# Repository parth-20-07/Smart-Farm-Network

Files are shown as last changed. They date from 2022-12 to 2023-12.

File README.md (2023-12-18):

<!-- omit from toc -->
# Smart Farm Network

**Table of Contents**

- [Introduction](#introduction)
- [Sensor Node](#sensor-node)
  - [Hardware Components](#hardware-components)
  - [Schematic](#schematic)
  - [PCB Design](#pcb-design)
- [Server Functionality](#server-functionality)
  - [Core Functions](#core-functions)
- [Setup and Operation](#setup-and-operation)
- [Data Handling and Alerts](#data-handling-and-alerts)
- [Customization and Expansion](#customization-and-expansion)
- [License](#license)
- [Design Details](#design-details)

# Introduction
The Smart Farm Network is a cutting-edge agricultural monitoring system designed to provide real-time insights into environmental conditions. Using a network of sensor nodes and a central server, it delivers detailed data analysis to help manage and optimize farming operations.

# Sensor Node
Equipped with sensors for temperature, humidity, lux, and CO2, each node collects data at set intervals. An integrated RTC ensures accurate timestamping. The nodes communicate with the server using BLE technology.

## Hardware Components
- **MicroUSB for Charging:** Ensures easy and accessible charging.
- **Battery Management:** Monitors and manages battery levels.
- **Power Conversion Units:** Provide the necessary voltages for different components.
- **ESP32 WROOM Module:** Processes and transmits the sensor data.
- **MicroSD Card Slot:** Enables data logging and storage.

## Schematic

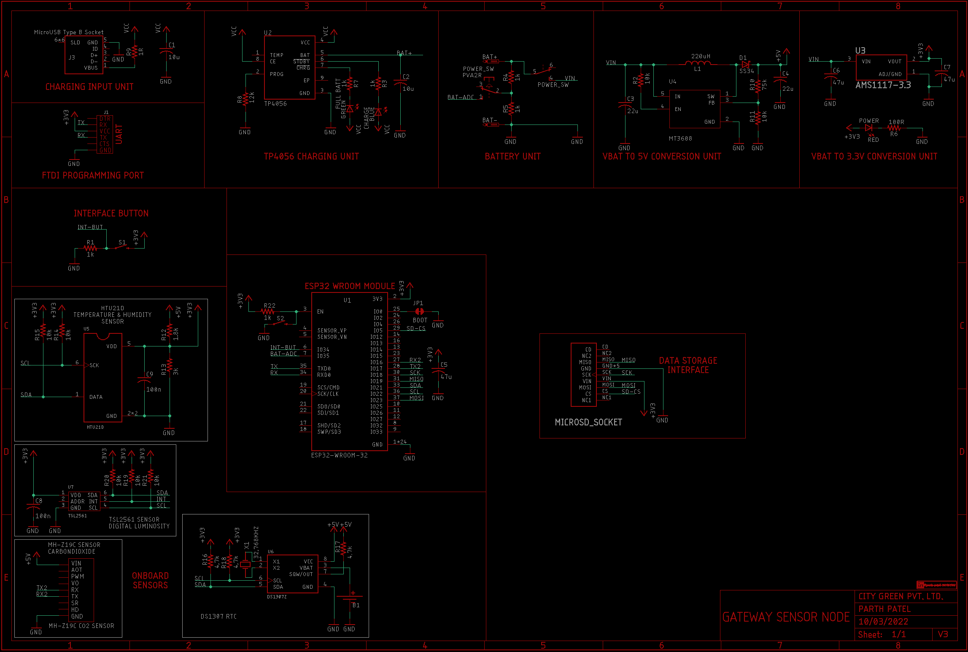
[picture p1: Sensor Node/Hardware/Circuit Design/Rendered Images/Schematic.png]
schematic


## PCB Design

**PCB Top View**

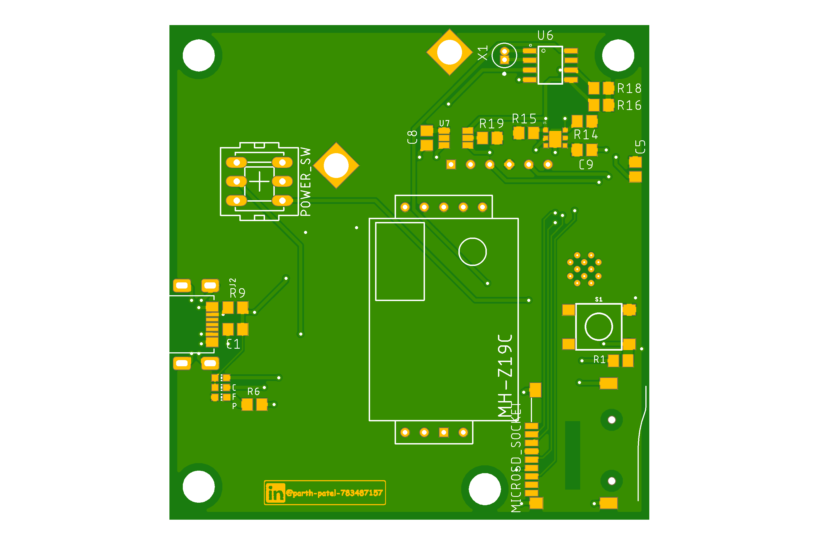
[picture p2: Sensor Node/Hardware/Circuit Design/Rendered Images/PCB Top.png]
pcb-top


**PCB Bottom View**

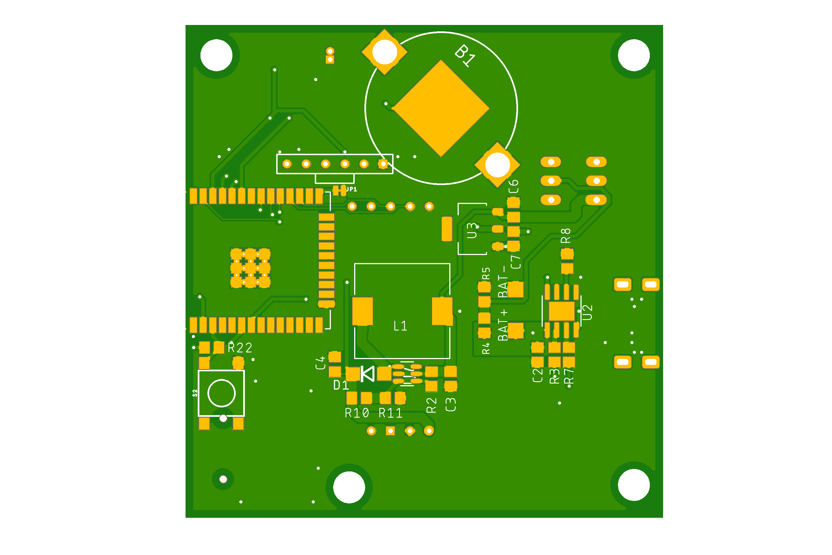
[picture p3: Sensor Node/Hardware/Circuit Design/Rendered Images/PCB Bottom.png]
pcb-bottom


# Server Functionality
The server firmware manages data from over 50 nodes, calculating averages, and issuing alerts if readings exceed thresholds. It features:

## Core Functions
- **Data Processing:** Analyzes incoming data and manages MQTT connections to Digital Ocean for cloud uploads.
- **Display Control:** Updates the HMI display with real-time data and alert statuses.
- **Configuration Management:** Offers a web server interface for device configuration.
- **OTA Updates:** Maintains system integrity with the latest firmware updates.

# Setup and Operation
1. **Assembling Sensor Nodes:** Follow the provided schematics to assemble the hardware.
2. **Installing Firmware:** Flash the sensor nodes and server with the respective firmware.
3. **Configuring the Network:** Connect the nodes to the server via BLE and set up the server's Wi-Fi and MQTT settings.
4. **Launching the System:** Power up the system, and it begins automatic data collection and analysis.

# Data Handling and Alerts
The system stores data in microSD cards and uploads it to the cloud. It calculates average values and displays alerts on the HMI screen if parameters exceed set thresholds.

# Customization and Expansion
The firmware's modular design allows for easy addition of new sensors or communication protocols.

# License
This project is licensed under the GNU General Public License v3.0. See [LICENSE.md](LICENSE.md) for details.

# Design Details

- Designed for: City Green Private Ltd.
- Designed by: [Parth Patel](mailto:parth.pmech@gmail.com)

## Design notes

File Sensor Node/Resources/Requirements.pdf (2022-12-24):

## BLE Node Features

1. Block Diagram:

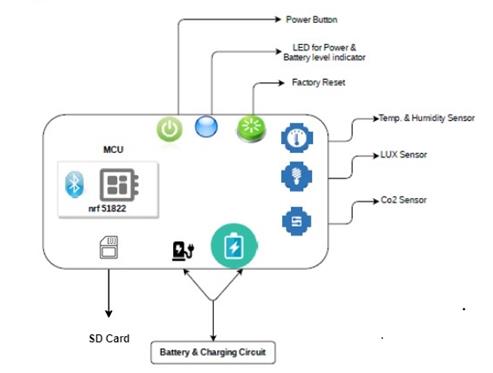
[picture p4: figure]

2. Node Should Send Data to Mobile & Gateway

Node Type

Node ID
Time Stamp
Sensor Data
3. If any of them (Mobile & Gateway) Not in Connection will store data up-to 10 days @ 5 min interval.
4. When connection comes back then it will send data again.
5. Sleep Mode enable when there is no connection.
6. Battery can be a 500mAH-1000mAH Rechargeable Li-Po Battery should charge within 1-2 Hr with Backup Of 5-6 Months.
7. LED Indicator for Power & Connection & Battery Level indicator. (2 LED with Multiple Color Combination)

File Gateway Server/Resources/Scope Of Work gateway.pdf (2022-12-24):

### Scope Of Work Gateway:-P1

It is capable of collecting data from several nodes via the BLE interface. It can store and send collected data to the cloud platform through WiFi. It will also feature a display unit for farm status.
Required Features:
1. Updating Wi-Fi Credentials via a html webpage.
2. The web page design is attached here

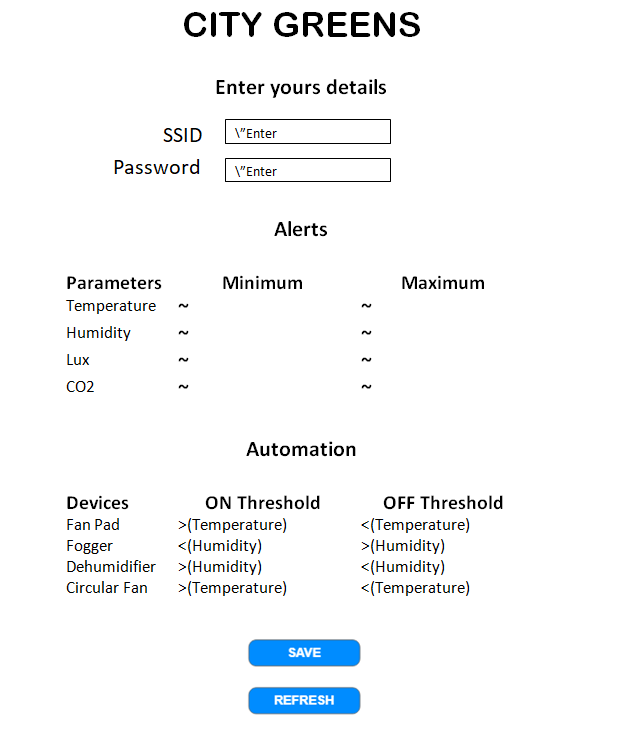
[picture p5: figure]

3. It save the Wi-Fi credentials & alerts data to its internal memory

4. It will check for OTA firmware updates via GitHub
5. Display Screen will Initialise
6. Scan for BLE nodes, identify our sensor nodes, make a connection with them and collect data via BLE
7. It will receive data from 8 Nodes Via BLE Communication.
8. Display Screen Design is shown below

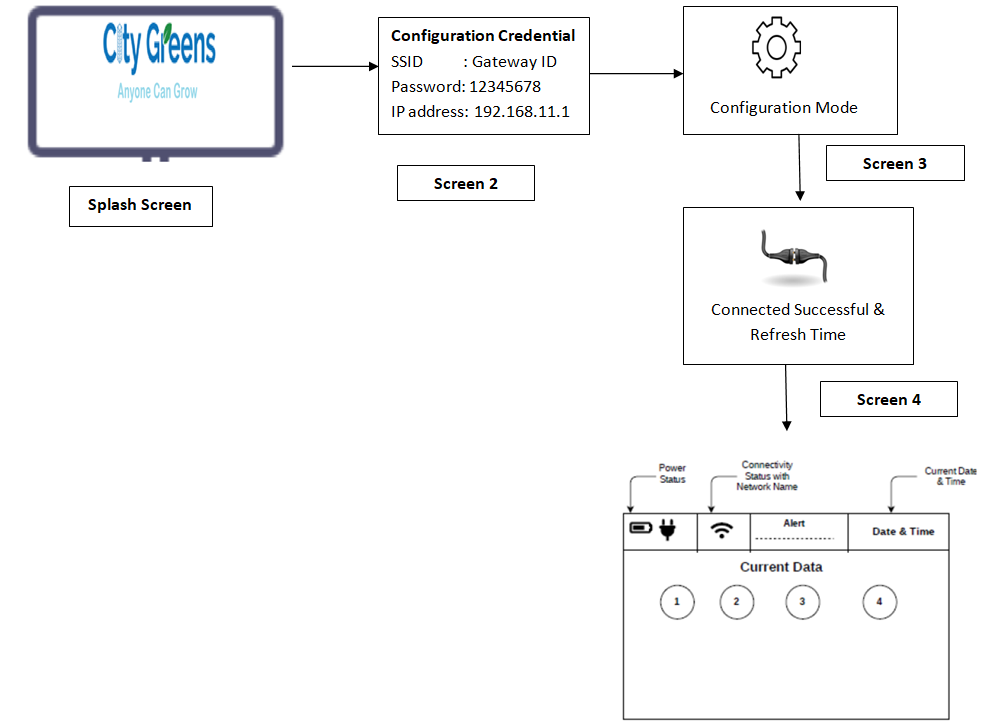
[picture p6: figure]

9. It will save/log the data to an SD card in .csv/.txt format. 10.Installation of MQTT software over the server (Digital Ocean Droplet).
11. The device will publish saved data to the cloud via MQTT.
12.It has a Temp./humidity (HTU21D) sensor on the PCB
13.Power Supply has 12V Battery (Li-ion 2500mAh-3s-11.1v-3c-3S1P Protected Battery Pack) with 12V 2A AC Adaptor
14.RTC will be used to update time.
15.There are three Push Buttons used in the gateway
Reset: it reset the settings of gateway & device will start from its default state; Configure button: it will be used as a manual interrupt to firmware for Wi-Fi & Alert Data Updated by User.
Power : It will be used as a Power On & Off Button for the gateway.
16.One LED will used for showing for Power on & off

### Gateway Display Screen Flow

1. Splash Screen

2. When user will push the configure button then display screen will show Configure page

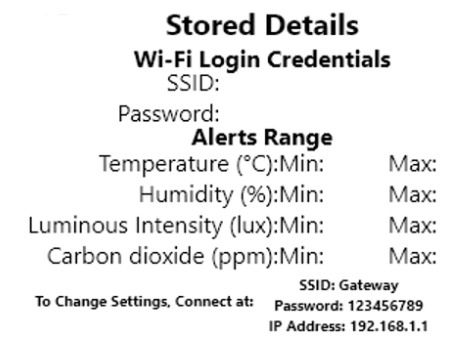
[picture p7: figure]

User will open shown ip address 192.168.1.1 in there url then a html page will open & user will fill the login credentials & save alerts value. The saved values shown on screen then the user will again push the configure button.firmware start to connect with given Wi-Fi credential.
3. After connecting with wi-fi firmware will start to search for an OTA firmware update. If any firmware update is there then firmware will start updating & display will show below screen.

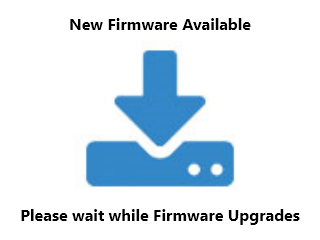
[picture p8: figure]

4. After OTA search main screen will show on display

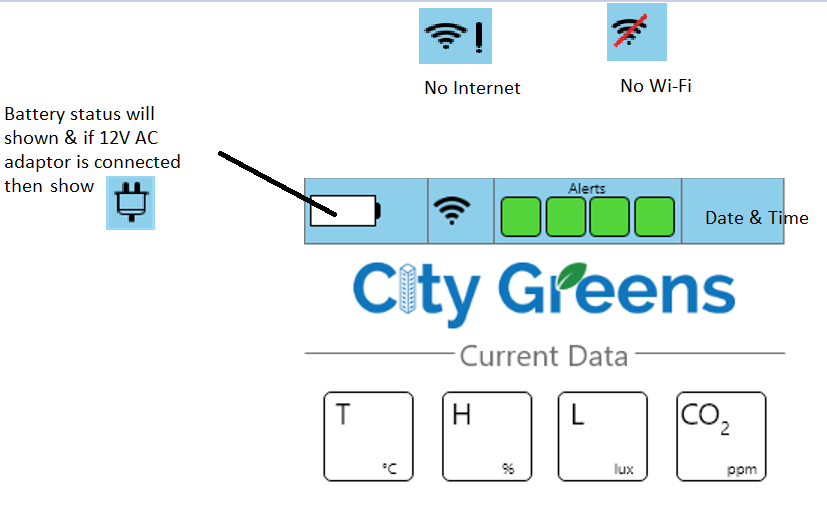
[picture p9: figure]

5. Search for available BLE Device ,Connect with them & receive data, when all the data has been collected from BLE Node then screen will update with following data. ❖ wifi_status true -> WiFi Connected, false -> WiFi Not Connected
❖ internet_status true -> Internet Connected, false -> Internet Not Connected
❖ temp_alert true -> Average Temperature in Range, false -> Average Temperature not in Range
❖ humidity_alert true -> Average Humidity in Range, false -> Average Humidity not in Range
❖ lux_alert true -> Average Lux in Range, false -> Average Lux not in Range
❖ co2_alert true -> Average CO2 in Range, false -> Average CO2 not in Range ❖ Date in format: DD/MM/YY
❖ Time in format: HH:MM
❖ average_temp Average Temperature from all nodes and onboard sensor
❖ average_humidity Average Humidity from all nodes and onboard sensor ❖ average_lux Average Lux from all nodes and onboard sensor
❖ average_co2 Average CO2 from all nodes and onboard sensor
6. Screen will update in every 5 min

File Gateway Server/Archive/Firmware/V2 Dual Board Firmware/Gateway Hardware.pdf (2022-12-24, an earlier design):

### Gateway

Features:

### 1. Power Supply

Power Source | Battery & 12V , 2 Amp AC Adaptor
Battery Type | Rechargeable / Replaceable
Battery Voltage | 4* 3.7V

### 2. Sensor Interface

Interface Type | Placement on PCB
Communication Interface | Digital (I2C)
Type | Temperature & Humidity Sensor (HTU21D)

### 3. Communication

Mode | Wireless
Technology | Bluetooth Low Energy (BLE) & Wi-Fi
Range | Upto 100 meter (outdoors)

### 4. Display

Size | Depend on characteristic shown on display .
Type | TFT
Interface | I2C or SPI

Block Diagram:

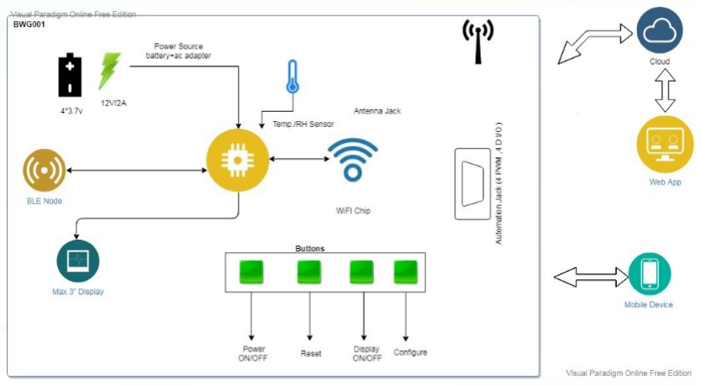
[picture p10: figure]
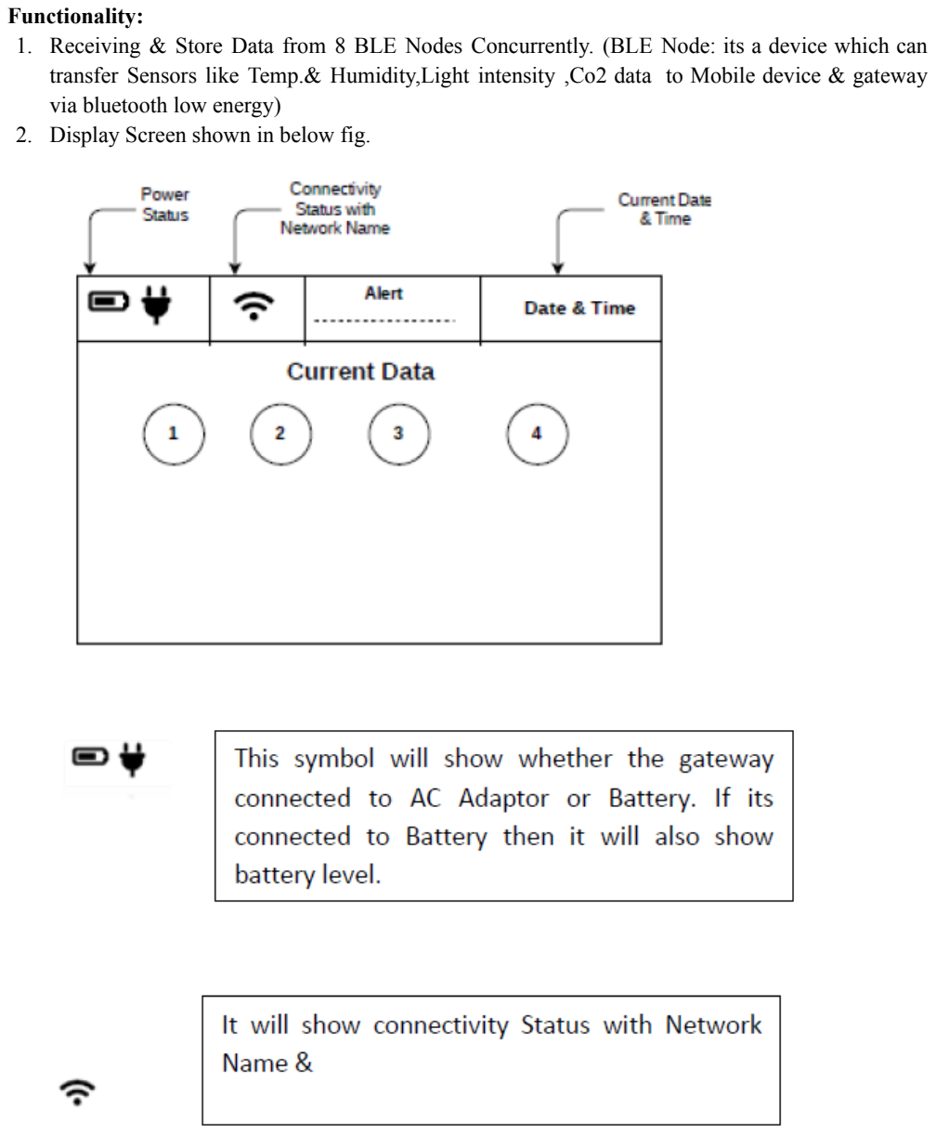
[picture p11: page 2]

Functionality:
1. Receiving & Store Data from 8 BLE Nodes Concurrently. (BLE Node: its a device which can transfer Sensors like Temp.& Humidity,Light intensity ,Co2 data to Mobile device & gateway via bluetooth low energy)
2. Display Screen shown in below fig.

Alert : Now any of the received parameter T, H, Lux, and Co2 has crossed any threshold over the display we can visualize using any icon like

Current Data: 1, 2, 3, 4 use for Current Mean Values of the all connected Nodes Sensor of the Farm

Date & Time: Show current time & data for gateway, we can set up date & Time Via internet.

3. Configuration Page for Setting Wi-Fi Credential :Use any device with a WiFi connection with a browser (computer, smartphone, tablet) to connect to the configuration page. If the configuration interface is protected by a password, you must first enter the password & now Enter the sensor threshold values & Automation Conditions,save all the data. The MCU will restart and connect to the configured WiFi network.
Example:

Click on configure Wi-Fi ,you will get the configure html page. Info button used for Tutorial purpose to show users how to connect with wi-fi & Save alert data , Exit buttons use for exit from the configure page.

SSID

Password

Alert :
Sensor | Max | Min
T | Float data | Float data
H | Float data | Float data
Lux | Integer Data | Integer Data
Co2 | Integer Data | Integer Data

Automation:

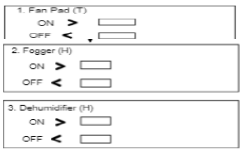
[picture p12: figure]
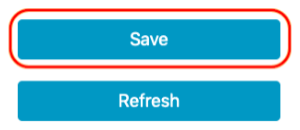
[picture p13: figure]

Select the WiFi network & enter the password & Save sensor threshold values & Automation Conditions . Click on Save to save data in memory. I will also provide data flow algo for showing how to generate alerts on TFT Display.

4. If the user buys just a gateway then it comes with features of sensing & logging Temperature & Humidity. We use HTU21D (o/p = I2C) in BLE Node, so we can also use this sensor in our gateway.
5. Connecting Cloud for Data Pushing. Data can be published in a Json document or Packet of declared Variables.
6. OTA Firmware Update.
7. Four Buttons use in block diagram
Reset: it reset the settings of gateway & device will start from its default state; Default state will be starting of your firmware algo & it will erase data stored in memory.
Configure button: it will be used as a manual interrupt to firmware for Wi-Fi & Alert Data Update by User.
Power : It will be used as a Power On & Off Button for the gateway.
Display: it will use On or Off The display on the gateway.
8. We should leave four analog and four digital pins for future use.

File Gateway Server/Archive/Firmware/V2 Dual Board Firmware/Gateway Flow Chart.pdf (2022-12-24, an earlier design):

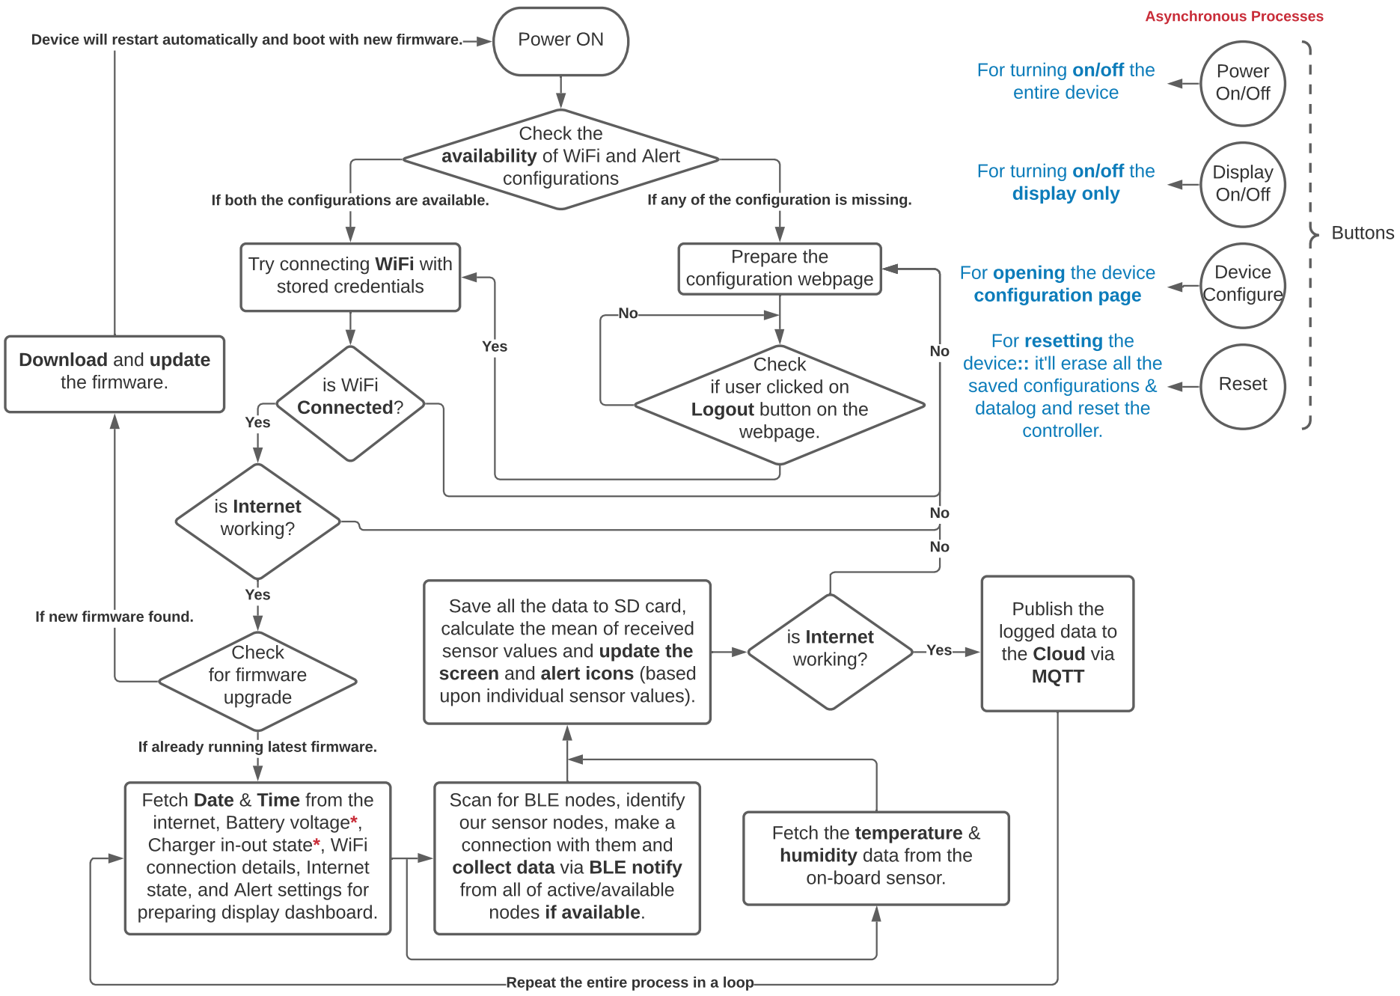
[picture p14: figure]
Power ON; Check the availability of WiFi and Alert configurations; Prepare the configuration webpage; If any of the configuration is missing.; Check if user clicked on Logout button on the webpage.; Try connecting WiFi with stored credentials; is WiFi Connected?; is Internet working?; Yes; Power On/Off; Display On/Off; Device Configure; Reset; Buttons; Asynchronous Processes; For turning on/off the entire device; For turning on/off the display only; For opening the device configuration page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

If both the configurations are available.

Device will restart automatically and boot with new firmware.

* This/these part(s) is/are left to be done entirely which is highly dependent on hardware but right now, all the other device functionalities are being covered in the firmware as instructed by the team.

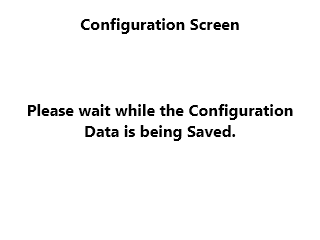
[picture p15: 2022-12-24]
Gateway Server/Display Files/Rendered Images/Save Configuration Data Screen.png

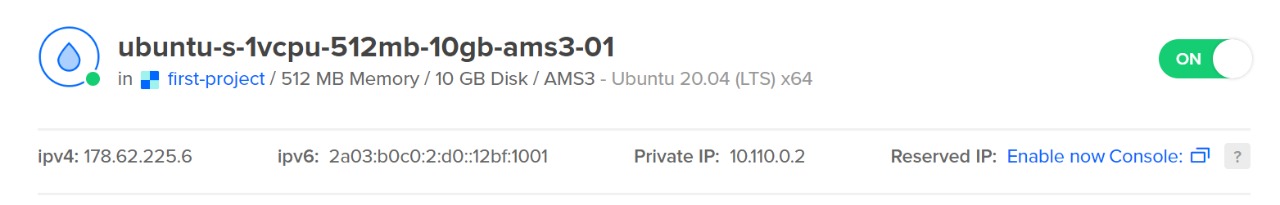
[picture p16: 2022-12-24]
Gateway Server/Resources/Digital Ocean Details.jpeg

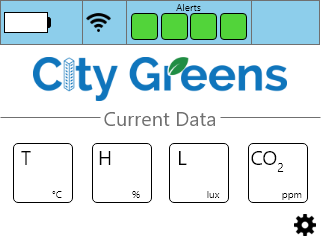
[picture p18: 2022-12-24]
Gateway Server/Display Files/Rendered Images/Background.png

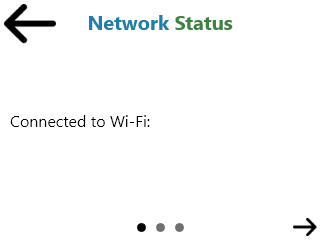
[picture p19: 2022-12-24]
Gateway Server/Display Files/Rendered Images/WiFi Page.png

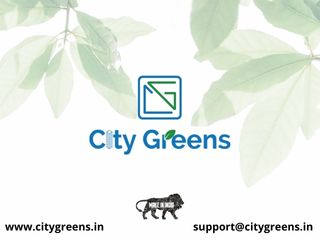
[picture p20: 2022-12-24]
Gateway Server/Display Files/Resources/Main Screen.jpg

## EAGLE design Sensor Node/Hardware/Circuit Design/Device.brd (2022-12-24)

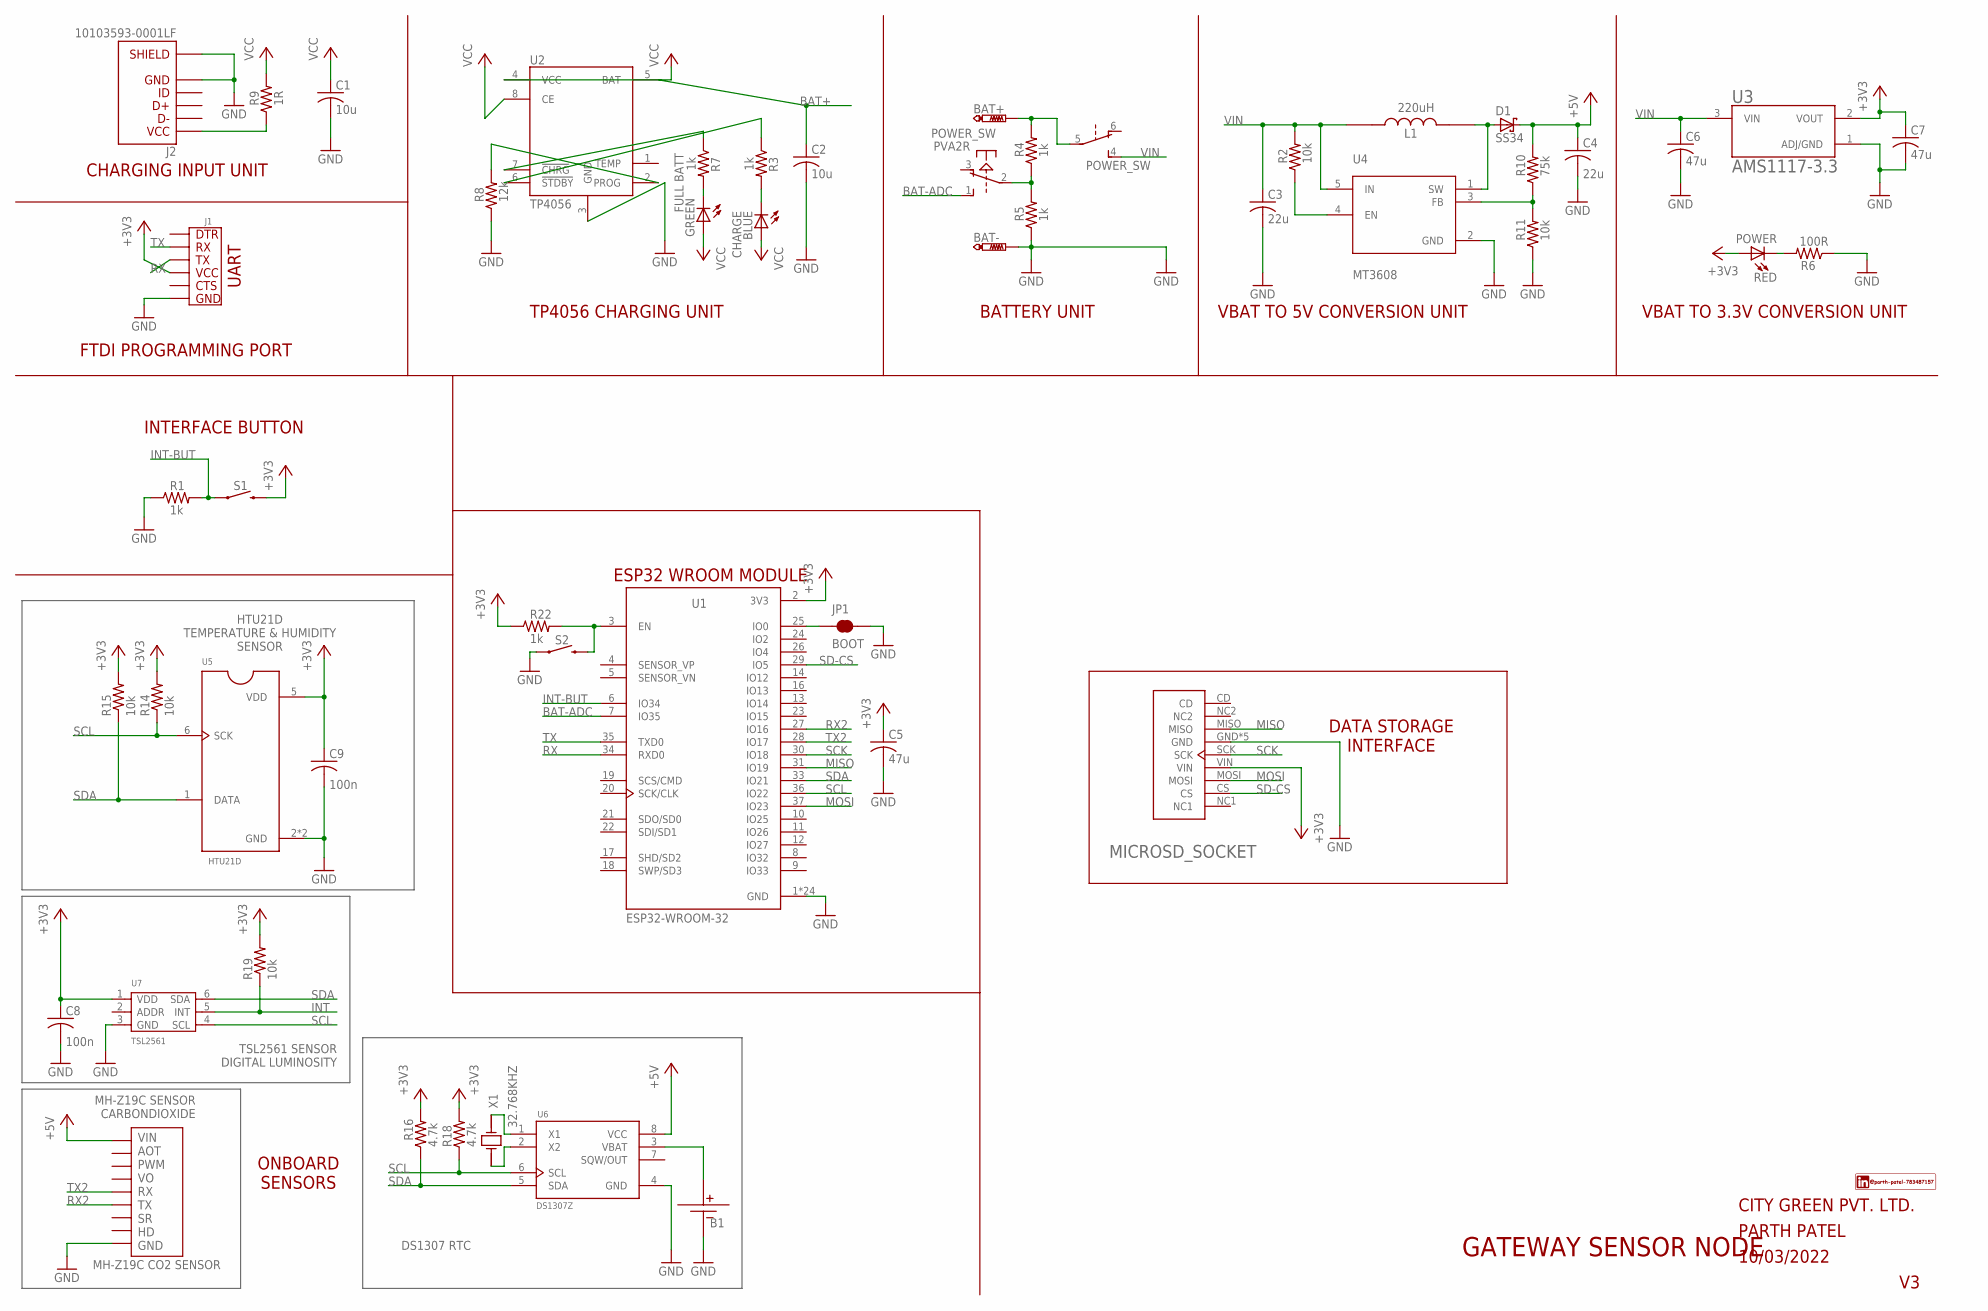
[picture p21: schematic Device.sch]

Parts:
B1: CR3032-METAL; CR2032-METAL
BAT+: PTR1TP20SQ; TP20SQ
BAT-: PTR1TP20SQ; TP20SQ
BLUE: CHARGE; CHIP-LED0603
C1, C2: 10u; C0805
C3, C4: 22u; C0805
C5, C6, C7: 47u; C0805
C8, C9: 100n; C0805
D1: SS34; DO214
GREEN: FULL BATT; CHIP-LED0603
J1: UART
J2: 10103593-0001LF; AMPHENOL_10103593-0001LF
JP1: BOOT; SMT-JUMPER_2_NC_TRACE_NO-SILK
L1: 220uH; IND_#B953AS-221M=P3
MICROSD_SOCKET: ST-TF-003A; SUNTECH_ST-TF-003A
POWER_SW: PVA2R
R1, R3, R4, R5, R7, R22: 1k; R0805
R2, R11, R14, R15, R19: 10k; R0805
R6: 100R; R0805
R8: 12k; R0805
R9: 1R; R0805
R10: 75k; R0805
R16, R18: 4.7k; R0805
RED: POWER; CHIP-LED0603
S1: MOMENTARY-SWITCH-SPST-SMD-6.2MM-TALL; TACTILE_SWITCH_SMD_6.2MM_TALL
S2: RST; TACTILE_SWITCH_SMD_6.2MM_TALL
U1: ESP32-WROOM-32; MODULE_ESP32-WROOM-32
U2: TP4056; SOP127P600X175-9N
U3: AMS1117-3.3; SOT229P700X180-4N
U4: MT3608; SOT95P280X145-6N
U5: HTU21D; QFN100P300X300X100-7N
U6: DS1307Z; SOIC127P600X175-8N
U7: TSL2561; TMB6-1.55-3.8X2.6MM
U$1: MH-Z19C
X1: 32.768KHZ; XTAL_AB38T-32.768KHZ

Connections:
+3V3: C5.1, C7.1, C8.1, C9.1, J1.VCC, MICROSD_SOCKET.VIN, R14.2, R15.2, R16.2, R18.2, R19.2, R22.1, RED.A, S1.B2 (2), U1.2 (3V3), U3.2 (VOUT), U5.5 (VDD), U7.1 (VDD)
+5V: C4.1, D1.C, R10.2, U6.8 (VCC), U$1.VIN
BAT+: BAT+.TP, C2.1, POWER_SW.5, R4.2, U2.5 (BAT)
BAT-ADC: POWER_SW.1 (S), U1.7 (IO35)
BAT-ADC-IN: POWER_SW.2, R4.1, R5.2
GND: B1.-VE1 (-VE), B1.-VE2 (-VE), BAT-.TP, C1.2, C2.2, C3.2, C4.2, C5.2, C6.2, C7.2, C8.2, C9.2, J1.GND, J2.5, J2.S1 (SHIELD), J2.S2 (SHIELD), J2.S3 (SHIELD), J2.S4 (SHIELD), J2.S5 (SHIELD), J2.S6 (SHIELD), JP1.2, MICROSD_SOCKET.GND, MICROSD_SOCKET.GND2 (GND), MICROSD_SOCKET.GND3 (GND), MICROSD_SOCKET.GND4 (GND), MICROSD_SOCKET.GND5 (GND), R1.1, R5.1, R6.1, R8.1, R11.1, S2.A2 (1), U1.1 (GND), U1.15 (GND), U1.38 (GND), U1.39_1 (GND), U1.39_2 (GND), U1.39_3 (GND), U1.39_4 (GND), U1.39_5 (GND), U1.39_6 (GND), U1.39_7 (GND), U1.39_8 (GND), U1.39_9 (GND), U1.39_10 (GND), U1.39_11 (GND), U1.39_12 (GND), U1.39_13 (GND), U1.39_14 (GND), U1.39_15 (GND), U1.39_16 (GND), U1.39_17 (GND), U1.39_18 (GND), U1.39_19 (GND), U1.39_20 (GND), U1.39_21 (GND), U2.3 (GND), U3.1 (ADJ/GND), U4.2 (GND), U5.2 (GND), U5.PAD (GND), U6.4 (GND), U7.3 (GND), U$1.GND
INT: R19.1, U7.5 (INT)
INT-BUT: R1.2, S1.A2 (1), U1.6 (IO34)
MISO: MICROSD_SOCKET.MISO, U1.31 (IO19)
MOSI: MICROSD_SOCKET.MOSI, U1.37 (IO23)
unnamed: R8.2, U2.2 (PROG)
unnamed: R6.2, RED.C
unnamed: J2.1, R9.1
unnamed: B1.+VE, U6.3 (VBAT)
unnamed: R2.1, U4.4 (EN)
unnamed: R3.1, U2.6 (!STDBY)
unnamed: R7.1, U2.7 (!CHRG)
unnamed: BLUE.C, R3.2
unnamed: GREEN.C, R7.2
unnamed: D1.A, L1.2, U4.1 (SW)
unnamed: R10.1, R11.2, U4.3 (FB)
unnamed: JP1.1, U1.25 (IO0)
unnamed: U6.2 (X2), X1.1
unnamed: R22.2, S2.B2 (2), U1.3 (EN)
unnamed: U6.1 (X1), X1.2
RX: J1.TX, U1.34 (RXD0)
RX2: U1.27 (IO16), U$1.TX
SCK: MICROSD_SOCKET.SCK, U1.30 (IO18)
SCL: R14.1, R18.1, U1.36 (IO22), U5.6 (SCK), U6.6 (SCL), U7.4 (SCL)
SD-CS: MICROSD_SOCKET.CS, U1.29 (IO5)
SDA: R15.1, R16.1, U1.33 (IO21), U5.1 (DATA), U6.5 (SDA), U7.6 (SDA)
TX: J1.RX, U1.35 (TXD0)
TX2: U1.28 (IO17), U$1.RX
VCC: BLUE.A, C1.1, GREEN.A, R9.2, U2.4 (VCC), U2.8 (CE)
VIN: C3.1, C6.1, L1.1, POWER_SW.4 (S), R2.2, U3.3 (VIN), U4.5 (IN)

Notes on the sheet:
ESP32 WROOM MODULE
MH-Z19C SENSOR CARBONDIOXIDE
TSL2561 SENSOR DIGITAL LUMINOSITY
ONBOARD SENSORS
INTERFACE BUTTON
DATA STORAGE INTERFACE
GATEWAY SENSOR NODE
CITY GREEN PVT. LTD.
PARTH PATEL
10/03/2022
TP4056 CHARGING UNIT
BATTERY UNIT
CHARGING INPUT UNIT
VBAT TO 5V CONVERSION UNIT
VBAT TO 3.3V CONVERSION UNIT
HTU21D TEMPERATURE & HUMIDITY SENSOR
DS1307 RTC
FTDI PROGRAMMING PORT

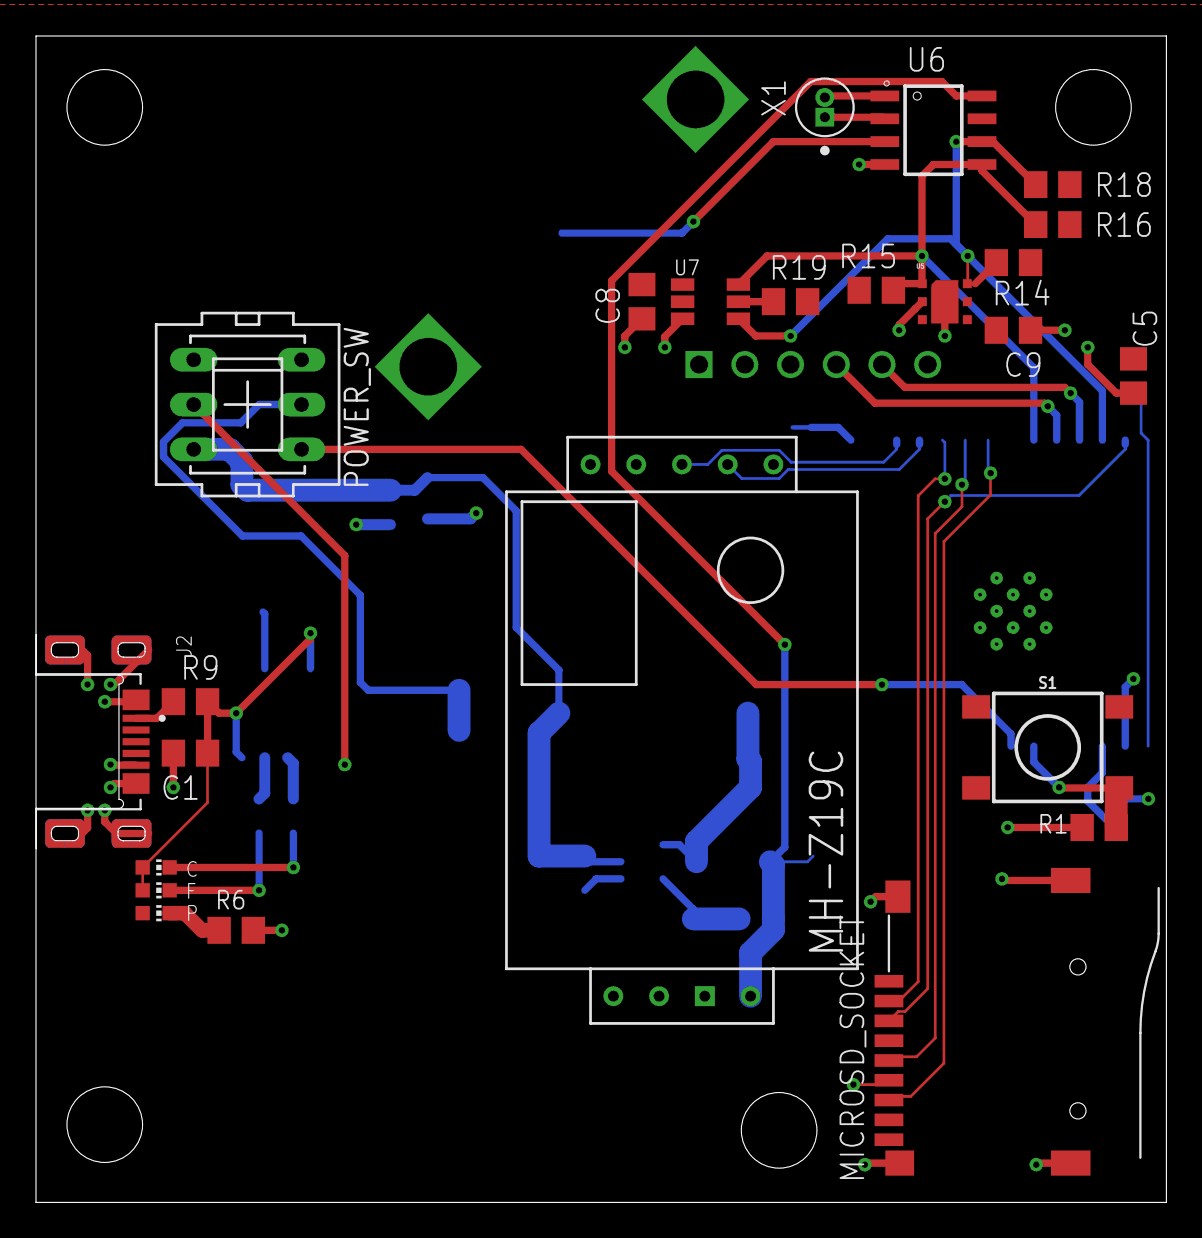
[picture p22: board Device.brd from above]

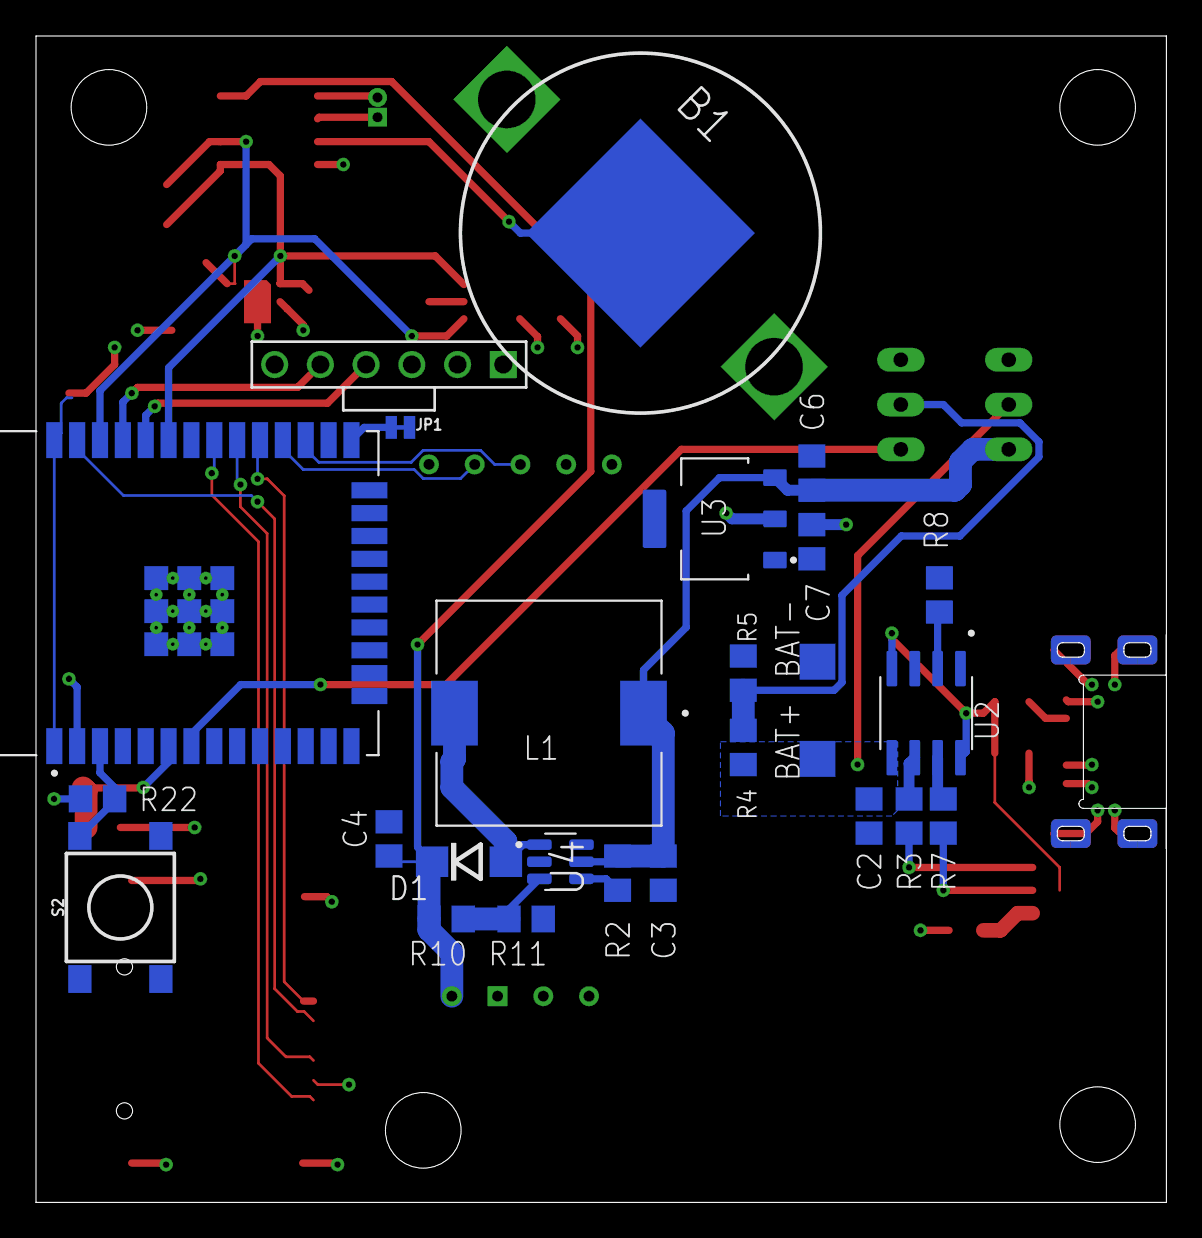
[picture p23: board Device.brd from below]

Board: 2 copper layers, 62.8 x 64.8 mm, 50 parts (26 on the bottom side), 35 nets.

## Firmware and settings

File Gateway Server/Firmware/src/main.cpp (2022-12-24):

/* -------------------------------------------------------------------------- */
/*                               BASIC LIBRARIES                              */
/* -------------------------------------------------------------------------- */
#include <Arduino.h>
#include "Pin_Connection.h"
#include "Variable_Declaration.h"
#include <pgmspace.h>
#include <ESP32Ping.h>

/* -------------------------------------------------------------------------- */
/*                                CUSTOM FILES                                */
/* -------------------------------------------------------------------------- */
#include "WiFi_Setup.cpp"
#include "MicroSD_Control.cpp"
#include "Display_Control.cpp"
#include "Time_Configuration.cpp"
#include "OTA_Configuration.cpp"
#include "Digital_Ocean_Connection.cpp"
#include "esp32_webserver.cpp"
#include "Sensor_Data_Collection.cpp"
#include "NimBLE_Communication.cpp"
#include "Variable_Declaration.h"

/* -------------------------------------------------------------------------- */
/*                              BASIC DEFINITION                              */
/* -------------------------------------------------------------------------- */

/* -------------------------------------------------------------------------- */
/*                             FUNCTION DEFINITION                            */
/* -------------------------------------------------------------------------- */
void read_digital_ocean_backlog_file(void);
void deparse_msg(String msg);
void calculate_averages_and_update_display(void);
void load_configuration_server(void);
void fetch_configuration_data(void);
void data_processing_operation(void);
void basic_operation(void);

/* -------------------------------------------------------------------------- */
/*                            FUNCTION DECLARATION                            */
/* -------------------------------------------------------------------------- */

/* ---------------------------- SD CARD FUNCTIONS --------------------------- */

void read_digital_ocean_backlog_file(void)
{
  Serial.println("Reading Data Backlog");
  change_screen("upload_screen");
  disconnect_from_mqtt();
  delay(500);
  connect_to_wifi();
  if (internet_connection_status)
  {
    if (!mqtt_setup_flag)
      mqtt_setup();

    connectToMqtt();
    delay(5000); // TODO: 5 sec delay for mqtt to connect
    Serial.println("Reading Backlog Files");

    {
      // Read Backlog 2 File
      File printFile = SD.open(DIGITAL_OCEAN_BACKLOG_FILE_2);
      bool complete_file_read = true;
      if (!printFile) // No digital_ocean File
        Serial.print("The text file cannot be opened");
      else // digital_ocean File Exists
      {
        Serial.println("Reading Backlog File 2");
        int lineIndex = 1;
        while (printFile.available())
        {
          String send_string = printFile.readStringUntil('\n');
          Serial.println((String)lineIndex + " : " + send_string);
          deparse_msg((String)send_string);
          sendData("node", rec_date, rec_time, nodeid, node_type, temp, humiditiy, lux, co2, battery_percentage);
          uint32_t mqtt_upload_millis = millis();
          while (((millis() - mqtt_upload_millis) < (DIGITAL_OCEAN_UPLOAD_TIME_IN_MINS * 60000)) && !mqtt_publish_confirmation)
            delay(1);
          if (mqtt_publish_confirmation)
            Serial.println("Publish Success!");
          else
          {
            Serial.println("Publish Failure!");
            complete_file_read = false;
            break;
          }
          lineIndex++;
        }
        printFile.close();
        if (complete_file_read)
          deleteFile(SD, DIGITAL_OCEAN_BACKLOG_FILE_2);
      }
    }

    {
      // Read Main Backlog File
      File printFile = SD.open(DIGITAL_OCEAN_BACKLOG_FILE);
      if (!printFile) // No digital_ocean File
      {
        Serial.print("The text file cannot be opened");
        digital_ocean_file_exists = false;
      }
      else // digital_ocean File Exists
      {
        Serial.println("Reading Backlog File 1");
        int lineIndex = 1;
        while (printFile.available())
        {
          String send_string = printFile.readStringUntil('\n');
          Serial.println((String)lineIndex + " : " + send_string);
          deparse_msg((String)send_string);
          sendData("node", rec_date, rec_time, nodeid, node_type, temp, humiditiy, lux, co2, battery_percentage);
          uint32_t mqtt_upload_millis = millis();
          while (((millis() - mqtt_upload_millis) < (DIGITAL_OCEAN_UPLOAD_TIME_IN_MINS * 60000)) && !mqtt_publish_confirmation)
            delay(1);
          if (mqtt_publish_confirmation)
            Serial.println("Publish Success!");
          else
          {
            Serial.println("Publish Failure!");
            appendFile(SD, DIGITAL_OCEAN_BACKLOG_FILE_2, send_string);
          }
          lineIndex++;
        }
        printFile.close();
        deleteFile(SD, DIGITAL_OCEAN_BACKLOG_FILE);
        digital_ocean_file_exists = false;
      }
    }
  }
  change_screen("main_screen");
  live_time = (String)hour + ":" + (String)minutes;
  update_display(wifi_connection_status, internet_connection_status, temp_alert, humidity_alert, lux_alert, co2_alert, live_date, live_time, temp, humiditiy, lux, co2);
  delay(50);
  return;
}

/* ------------------------ DATA PROCESSING FUNCTION ------------------------ */
void deparse_msg(String deparse_msg)
{
  // Seperating the csv string
  String cmd = deparse_msg.substring(0, 4);
  if (cmd == "hist")
  {
    String msg = deparse_msg.substring(5);
    appendFile(SD, DIGITAL_OCEAN_BACKLOG_FILE, msg);
    digital_ocean_file_exists = true;
    return;
  }

  String msg = "";
  if (cmd == "live")
    msg = deparse_msg.substring(5);
  else
    msg = deparse_msg;

  Serial.println("Deparsing Message: " + msg);
  String params[10];
  char seperation_token = ',';
  uint8_t last_pos = 0;
  uint8_t param_index = 0;
  for (size_t i = 0; i < msg.length(); i++)
  {
    if (msg[i] == seperation_token)
    {
      params[param_index] = msg.substring(last_pos, i);
      last_pos = i + 1;
      param_index++;
    }
  }
  params[param_index] = msg.substring(last_pos);

  // Seperating the colon seperated values
  String param_values[10];
  String param_identifiers[10];
  char break_token = ':';
  for (size_t i = 0; i < param_index + 1; i++)
  {
    String parameter = params[i];
    for (size_t j = 0; j < parameter.length(); j++)
      if (parameter[j] == break_token)
      {
        param_identifiers[i] = parameter.substring(0, j);
        param_values[i] = parameter.substring(j + 1);
      }
  }

  node_type = "", nodeid = "", rec_date = "", rec_time = "", temp = 0, humiditiy = 0, lux = 0, co2 = 0, battery_percentage = 0;

  for (size_t i = 0; i < 10; i++)
  {
    if (param_identifiers[i] == "I")
      nodeid = param_values[i];
    else if (param_identifiers[i] == "D")
      rec_date = param_values[i];
    else if (param_identifiers[i] == "G")
      rec_time = param_values[i];
    else if (param_identifiers[i] == "N")
      node_type = param_values[i];
    else
    {
      char char_value[param_values[i].length()];
      strcpy(char_value, param_values[i].c_str());
      if (param_identifiers[i] == "T")
        temp = atof(char_value);
      else if (param_identifiers[i] == "H")
        humiditiy = atoi(char_value);
      else if (param_identifiers[i] == "L")
        lux = atoi(char_value);
      else if (param_identifiers[i] == "C")
        co2 = atoi(char_value);
      else if (param_identifiers[i] == "B")
        battery_percentage = atoi(char_value);
    }
  }

  if (temp != 0)
  {
    database_temp[temp_values] = temp;
    if ((database_temp[temp_values] < params_range[0]) || (database_temp[temp_values] > params_range[1]))
      temp_alert = true;
    temp_values++;
  }
  if (humiditiy != 0)
  {
    database_humiditiy[humidity_values] = humiditiy;
    if ((database_humiditiy[humidity_values] < params_range[2]) || (database_humiditiy[humidity_values] > params_range[3]))
      humidity_alert = true;
    humidity_values++;
  }
  if (lux != 0)
  {
    database_lux[lux_values] = lux;
    if ((database_lux[lux_values] < params_range[4]) || (database_lux[lux_values] > params_range[5]))
      lux_alert = true;
    lux_values++;
  }
  if (co2 != 0)
  {
    database_co2[co2_values] = co2;
    if ((database_co2[co2_values] < params_range[6]) || (database_co2[co2_values] > params_range[7]))
      co2_alert = true;
    co2_values++;
  }
  return;
}

void calculate_averages_and_update_display(void)
{
  Serial.println("Calculating Average to update display");
  calculated_first_average = true;

  double total_temperature_sum = 0;
  for (size_t i = 0; i < temp_values; i++)
    total_temperature_sum += database_temp[i];
  Serial.println("Temp Sum: " + (String)total_temperature_sum);
  Serial.println("Temp Values: " + (String)temp_values);
  uint16_t average_temp = 0;
  if (temp_values != 0)
    average_temp = uint8_t(total_temperature_sum / temp_values);
  Serial.println("Temp average: " + (String)average_temp);

  double total_humidity_sum = 0;
  for (size_t i = 0; i < humidity_values; i++)
    total_humidity_sum += database_humiditiy[i];
  Serial.println("Humidity Sum: " + (String)total_humidity_sum);
  Serial.println("Humidity Values: " + (String)humidity_values);
  uint16_t average_humidity = 0;
  if (humidity_values != 0)
    average_humidity = uint8_t(total_humidity_sum / humidity_values);
  Serial.println("Humidity average: " + (String)average_humidity);

  double total_lux_sum = 0;
  for (size_t i = 0; i < lux_values; i++)
    total_lux_sum += database_lux[i];
  Serial.println("Lux Sum: " + (String)total_lux_sum);
  Serial.println("Lux Values: " + (String)lux_values);
  uint16_t average_lux = 0;
  if (lux_values != 0)
    average_lux = uint16_t(total_lux_sum / lux_values);
  Serial.println("Lux average: " + (String)average_lux);

  double total_co2_sum = 0;
  for (size_t i = 0; i < co2_values; i++)
    total_co2_sum += database_co2[i];
  Serial.println("CO2 Sum: " + (String)total_co2_sum);
  Serial.println("CO2 Values: " + (String)co2_values);
  uint16_t average_co2 = 0;
  if (co2_values != 0)
    average_co2 = uint16_t(total_co2_sum / co2_values);
  Serial.println("CO2 average: " + (String)average_co2);
  connect_to_wifi();
  if (internet_connection_status)
  {
    if (!mqtt_setup_flag)
      mqtt_setup();
    connectToMqtt();
    sendData("average", live_date, live_time, "", "", average_temp, average_humidity, average_lux, average_co2, 0);
  }
  live_time = (String)hour + ":" + (String)minutes;
  update_display(wifi_connection_status, internet_connection_status, temp_alert, humidity_alert, lux_alert, co2_alert, live_date, live_time, average_temp, average_humidity, average_lux, average_co2);
  temp_values = 0, humidity_values = 0, lux_values = 0, co2_values = 0, temp_alert = false, humidity_alert = false, lux_alert = false, co2_alert = false;
  memset(database_temp, 0, MAX_NODES);
  memset(database_humiditiy, 0, MAX_NODES);
  memset(database_lux, 0, MAX_NODES);
  memset(database_co2, 0, MAX_NODES);
  lastMillis = millis();
}

/* --------------------------- WEBSERVER FUNCTION --------------------------- */
void load_configuration_server(void)
{
  Serial.println("Loading Configuration Screen");
  change_screen("conf_screen"); // Load Configuration screen on display
  delay(2000);
  launch_webserver();
  Serial.println("Saving Configuration Data");
  change_screen("save_screen");
  Serial.println("Saving Data from Webserver");
  Serial.println("--------------------------------");
  writeFile(SD, SSID_FILE, (String)ssid);
  Serial.println("--------------------------------");
  Serial.println("--------------------------------");
  writeFile(SD, PASSWORD_FILE, (String)password);
  Serial.println("--------------------------------");
  for (size_t i = 0; i < NUMBER_OF_PARAMS; i++)
  {
    Serial.println("--------------------------------");
    String str_path = "/" + (String)i + ".txt";
    writeFile(SD, str_path, (String)params_range[i]);
    Serial.println("--------------------------------");
    delay(10);
  }
  Serial.println("Restarting Device");
  delay(10);
  ESP.restart();
}

/* ------------------------ DEVICE STARTUP FUNCTIONS ------------------------ */

void fetch_configuration_data(void)
{
  String fetched_ssid = read_single_line_data_from_sd_card(SSID_FILE); // Retrieving SSID
  strcpy(ssid, fetched_ssid.c_str());
  String fetched_password = read_single_line_data_from_sd_card(PASSWORD_FILE); // Retrieving Password
  strcpy(password, fetched_password.c_str());

  for (size_t i = 0; i < NUMBER_OF_PARAMS; i++) // Retrieving Parameter Range Values
  {
    String str_path = "/" + (String)i + ".txt";
    String file_value = read_single_line_data_from_sd_card(str_path);
    char file_value_char[file_value.length()];
    strcpy(file_value_char, file_value.c_str());
    params_range[i] = atoi(file_value_char);
    delay(10);
  }

  Serial.println("Firmware Version: " + (String)firmware_version);
  Serial.println("Firmware Version Link: " + (String)URL_fw_Version);
  Serial.println("Firmware File Link: " + (String)URL_fw_Bin);
  Serial.println("Read Complete");
}

void data_processing_operation(void)
{
  if ((msg_list_number > 0) && ble_msg_recieve_complete) // Read any message stored in array during BLE Scan
  {
    Serial.println("================================================================");
    Serial.println("Processing Incoming Data");
    for (size_t i = 0; i < msg_list_number; i++)
    {
      deparse_msg(incoming_ble_message_list[i]);
      String str_msg = incoming_ble_message_list[i].substring(5);
      appendFile(SD, DIGITAL_OCEAN_BACKLOG_FILE, str_msg);
      digital_ocean_file_exists = true;
      if (!calculated_first_average && (incoming_ble_message_list[i].substring(4) == "live"))
      {
        live_time = (String)hour + ":" + (String)minutes;
        update_display(wifi_connection_status, internet_connection_status, temp_alert, humidity_alert, lux_alert, co2_alert, live_date, live_time, temp, humiditiy, lux, co2);
      }
      delay(100);

      for (size_t j = 0; j < sizeof(incoming_ble_message_list[i]); j++)
        incoming_ble_message_list[i][j] = 0;
    }
    msg_list_number = 0;
    ble_msg_recieve_complete = false;
  }
}

void basic_operation(void)
{
  // Serial.println("Raw Battery ADC: " + (String)analogRead(BATTERY_ADC_PIN));// TODO: Uncomment this line when battery ADC needs to be measured.

  if (digitalRead(CONFIGURATION_BUTTON) == HIGH) // To Load Configuration Screen
    load_configuration_server();

  if (((millis() - last_sensor_fetch_millis) > (ONBOARD_SENSOR_DATA_REFRESH_TIME_IN_MINS * 60000)) || (first_boot)) // Reading onboard sensor data
  {
    Serial.println("================================");
    first_boot = false;
    Serial.println("Fetching onboard Sensor Values");
    String msg = "live";
    rtc_get_time();
    msg += ",N:TH,I:00000"; // Starting to write message
    msg += ",D:" + live_date + ",G:" + live_time;
    msg += ",T:" + (String)read_onboard_temperature() + ",H:" + (String)read_onboard_humidity();
    msg += ",B:" + (String)read_battery_level();
    deparse_msg(msg);
    String str_msg = msg.substring(5);
    appendFile(SD, DIGITAL_OCEAN_BACKLOG_FILE, str_msg);
    digital_ocean_file_exists = true;
    last_sensor_fetch_millis = millis();
    live_time = (String)hour + ":" + (String)minutes;
    update_display(wifi_connection_status, internet_connection_status, temp_alert, humidity_alert, false, false, live_date, live_time, (uint8_t)read_onboard_temperature(), (uint8_t)read_onboard_humidity(), 0, 0);
    Serial.println("================================");
  }

  if (((millis() - lastMillis) > DISPLAY_UPDATE_TIME) || (temp_values == MAX_NODES - 1) || (humidity_values == MAX_NODES - 1) || (lux_values == MAX_NODES - 1) || (co2_values == MAX_NODES - 1)) // update display with new average values
    calculate_averages_and_update_display();

  if ((millis() - last_internet_refresh) > 300000) // Check Internet Connection periodically
  {
    Serial.println("================================");
    Serial.println("Checking Internet Status");
    bool internet_status = check_internet_connection_status();
    if (!internet_connection_status)
      connect_to_wifi();
    set_wifi_internet_flag(wifi_connection_status, internet_connection_status);
    last_internet_refresh = millis();
    Serial.println("================================");
  }

  if ((millis() - last_millis_time_update) > 60000) // Update time on display
  {
    Serial.println("================================");
    Serial.println("Updating Display Time");
    printLocalTime();
    update_data_on_screen("date", "txt", 0, live_date); // Setting Date
    update_data_on_screen("time", "txt", 0, live_time); // Setting Time
    last_millis_time_update = millis();
    Serial.println("================================");
  }

  String recieved_message = read_nextion_input_message(); // Check if nextion display sent any msg
  if (recieved_message == "main")
  {
    Serial.println("Loading Main Screen");
    change_screen("main_screen");
    live_time = (String)hour + ":" + (String)minutes;
    update_display(wifi_connection_status, internet_connection_status, temp_alert, humidity_alert, lux_alert, co2_alert, live_date, live_time, temp, humiditiy, lux, co2);
  }
  else if (recieved_message == "ssid")
  {
    change_screen("ssid_screen");
    delay(500);
    update_data_on_screen("ssid", "txt", 0, (String)ssid);
    update_data_on_screen("password", "txt", 0, (String)password);
  }
  else if (recieved_message == "alerts")
  {
    change_screen("alert_screen");
    delay(500);
    update_data_on_screen("min_temp", "val", params_range[0], "");
    update_data_on_screen("max_temp", "val", params_range[1], "");
    update_data_on_screen("min_humi", "val", params_range[2], "");
    update_data_on_screen("max_humi", "val", params_range[3], "");
    update_data_on_screen("min_lux", "val", params_range[4], "");
    update_data_on_screen("max_lux", "val", params_range[5], "");
    update_data_on_screen("min_co2", "val", params_range[6], "");
    update_data_on_screen("max_co2", "val", params_range[7], "");
  }
  else if (recieved_message == "auto")
  {
    change_screen("auto_screen");
    delay(500);
    update_data_on_screen("min_fan", "val", params_range[8], "");
    update_data_on_screen("max_fan", "val", params_range[9], "");
    update_data_on_screen("min_fog", "val", params_range[10], "");
    update_data_on_screen("max_fog", "val", params_range[11], "");
    update_data_on_screen("min_deh", "val", params_range[12], "");
    update_data_on_screen("max_deh", "val", params_range[13], "");
    update_data_on_screen("min_cfan", "val", params_range[14], "");
    update_data_on_screen("max_cfan", "val", params_range[15], "");
  }
}

/* -------------------------------------------------------------------------- */
/*                                 DEVICE CODE                                */
/* -------------------------------------------------------------------------- */
void setup()
{
  Serial.begin(115200); // open serial via USB to PC on default port
  Serial.println("\n\n=================================================");
  Serial.println("Setting Up Device");
  setup_pins();
  setup_sensors();
  setup_display();
  setup_microsd();
  fetch_configuration_data();

  if ((((String)ssid).length() == 0) || (((String)password).length() == 0))
    load_configuration_server();

  wifi_connection_status = connect_to_wifi();
  rtc_setup();

  if (internet_connection_status) // Checking for OTA
  {
    connect_to_ntp();
    if (internet_connection_status)
    {
      //   Serial.println("IP address: ");
      //   Serial.println(WiFi.localIP());
      //   bool new_firmware_version_available = false;
      //   for (size_t i = 0; i < 60; i++)
      //   {
      //     switch (check_for_new_firmware())
      //     {
      //     case 0:
      //       Serial.println("Trying again!");
      //       break;
      //     case 1:
      //       new_firmware_version_available = true;
      //       break;
      //     case 2:
      //       new_firmware_version_available = false;
      //       break;
      //     }
      //     break;
      //   }
      // if (new_firmware_version_available)//TODO: Undo Comment OTA When testing is complete
      // {
      //   Serial.println("Loading Firmware Upgrade Page");
      //   change_screen("firm_screen");
      //   update_firmware();
      //   delay(100);
      //   Serial.println("Firmware Update Complete.\n\nRestarting Device.");
      //   ESP.restart();
      // }
      // else
      mqtt_setup();
      read_digital_ocean_backlog_file(); // TODO: Enable this is digital_ocean data is high priority than BLE
    }
  }

  uint32_t millis_timer = millis();
  lastMillis = millis_timer;
  last_sensor_fetch_millis = millis_timer;
  last_internet_refresh = millis_timer;
  last_millis_time_update = millis_timer + 70000;
  last_digital_ocean_upload = millis_timer;
  Serial.println("Device Setup Complete");
  change_screen("main_screen");
  Serial.println("=================================================\n\n");
  setup_ble();
}

void loop()
{
  read_msg();
  basic_operation();
  data_processing_operation();

  if (digital_ocean_file_exists)
  {
    if ((millis() - last_digital_ocean_upload) > (DIGITAL_OCEAN_UPLOAD_TIME_IN_MINS * 60000)) // TODO: Change this to set the digital_ocean Upload Interval
    {
      stop_ble();
      data_processing_operation();
      read_digital_ocean_backlog_file();
      setup_ble();
      last_digital_ocean_upload = millis();
    }
  }
}

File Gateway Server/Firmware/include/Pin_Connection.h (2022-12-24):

#ifndef Pin_Connection_h
#define Pin_Connection_h
#include "Arduino.h"

// GPIO Pins
#define ESP32_GPIO_2 2
#define ESP32_GPIO_4 4
#define ESP32_GPIO_5 5 // SD Card Chip Select
#define ESP32_GPIO_12 12
#define ESP32_GPIO_13 13 // RST Pin for Server Board
#define ESP32_GPIO_14 14
#define ESP32_GPIO_15 15
#define ESP32_GPIO_16 16
#define ESP32_GPIO_17 17
#define ESP32_GPIO_25 25
#define ESP32_GPIO_26 26
#define ESP32_GPIO_27 27
#define ESP32_GPIO_32 32 // Configuration Button
#define ESP32_GPIO_33 33
#define ESP32_GPIO_34 34 // Battery Input Pin
#define ESP32_GPIO_35 35 // Charger Input Pin
#define ESP32_GPIO_39 39
#define ESP32_GPIO_36 36

// Communication Pins
#define ESP_SPI_SCK 18  // SPI Clock
#define ESP_SPI_MISO 19 // SPI Master In Slave Out
#define ESP_SPI_MOSI 23 // SPI Master Out Slave In
#define ESP_I2C_SDA 21  // I2C Serial Data
#define ESP_I2C_SCL 22  // T2C Serial Clock

/* ----------------------------- SD CARD MODULE ----------------------------- */
// 3V3	= 3.3V
// MOSI	= ESP_SPI_MOSI
// CLK	= ESP_SPI_SCK
// MISO	= ESP_SPI_MISO
// GND	= GND
#define SD_CHIP_SELECT ESP32_GPIO_5

/* ---------------------------- INTERFACE BUTTON ---------------------------- */
#define CONFIGURATION_BUTTON ESP32_GPIO_32

/* ---------------------------- POWER CONNECTION ---------------------------- */
#define BATTERY_INPUT ESP32_GPIO_34
#define CHARGER_INPUT ESP32_GPIO_35

void setup_pins(void)
{
    pinMode(BATTERY_INPUT, INPUT);
    pinMode(CHARGER_INPUT, INPUT);
    pinMode(CONFIGURATION_BUTTON, INPUT);
    Serial.println("Pins Setup Complete");
}

#endif

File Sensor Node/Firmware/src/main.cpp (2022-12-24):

#include <Arduino.h>
#include "Pin_Connection.h"
#include "Variable_Declaration.h"
#include "Device_Configration.h"
#include "NimBLE_Configuration.cpp"
#include "Sensor_Data_Collection.cpp"
#include "RTC_Configuration.cpp"
#include "Historical_data_log.cpp"
#include "Battery_Configuration.cpp"
#include "EEPROM.h"

/* -------------------------------------------------------------------------- */
/*                            VARIABLE DECLARATION                            */
/* -------------------------------------------------------------------------- */
#define BUTTON_PIN_BITMASK 0x200000000 // 2^33 in hex

/* -------------------------------------------------------------------------- */
/*                            FUNCTION DECLARATION                            */
/* -------------------------------------------------------------------------- */
uint8_t print_wakeup_reason()
{
  esp_sleep_wakeup_cause_t wakeup_reason;
  wakeup_reason = esp_sleep_get_wakeup_cause();
  switch (wakeup_reason)
  {
  case ESP_SLEEP_WAKEUP_EXT0:
    Serial.println("Wakeup caused by external signal using RTC_IO");
    break;
  case ESP_SLEEP_WAKEUP_EXT1:
    Serial.println("Wakeup caused by external signal using RTC_CNTL");
    break;
  case ESP_SLEEP_WAKEUP_TIMER:
    Serial.println("Wakeup caused by timer");
    break;
  case ESP_SLEEP_WAKEUP_TOUCHPAD:
    Serial.println("Wakeup caused by touchpad");
    break;
  case ESP_SLEEP_WAKEUP_ULP:
    Serial.println("Wakeup caused by ULP program");
    break;
  default:
    Serial.printf("Wakeup was not caused by deep sleep: %d\n", wakeup_reason);
    break;
  }
  return wakeup_reason;
}

bool recieved_data_via_ble(void)
{
  recieved_data_flag = false;
  String msg = read_recieved_message();
  Serial.println("Rec. Command: " + msg);
  String cmd_msg, cmd_instruction;
  {
    char token = ',';
    uint8_t msg_length = msg.length();
    for (size_t i = 0; i < msg_length; i++)
      if (msg[i] == token)
      {
        cmd_msg = msg.substring(0, i);
        cmd_instruction = msg.substring(i + 1, msg_length - 2);
        i = msg_length;
      }
    Serial.println("CMD MSG: " + cmd_msg);
    Serial.println("CMD INSTRUCTION: " + cmd_instruction);
  }

  if (cmd_msg == BLE_UPDATE_TIME_COMMAND)
    set_time(cmd_instruction);
  else if (cmd_msg == BLE_UPDATE_SYNC_COMMAND)
    read_historical_data();
  else if (cmd_msg == BLE_UPDATE_SLEEP_COMMAND)
    return true; // False is returned only when device is needed to sleep
  else
    Serial.println("Unknown Message format");
  return false;
}

void fetch_node_id(void)
{

  EEPROM.begin(NODE_ID_SIZE);
  String node_id[NODE_ID_SIZE];
  uint8_t first_id = EEPROM.read(0);
  if (first_id > 9)
  {
    Serial.println("Generating New Node ID");
    for (size_t i = 0; i < NODE_ID_SIZE; i++)
    {
      uint8_t id = random(0, 10);
      Serial.println("Write Node ID [" + (String)i + "]: " + (String)id);
      EEPROM.write(i, id);
    }
    EEPROM.commit();
  }

  for (size_t i = 0; i < NODE_ID_SIZE; i++)
  {
    node_id[i] = (String)EEPROM.read(i);
    NODE_ID += node_id[i];
  }
  Serial.println("Node ID: " + NODE_ID);
}

void setup()
{
  Serial.begin(115200);
  Serial.println("\n\n/* -------------------------- STARTING DEVICE SETUP ------------------------- */");
  fetch_node_id();
  bool external_wakeup = false;

#ifdef DUMMY_NODE
  Serial.println("In Dummy Mode");
  node_type = "THCL";
#else
  uint8_t wakeup_reason_flag;
  Serial.println("In Operational Mode");
  node_type = setup_sensors();
  wakeup_reason_flag = print_wakeup_reason();
  if (wakeup_reason_flag == ESP_SLEEP_WAKEUP_EXT0) // Wakeup caused by user
    external_wakeup = true;
  setup_rtc();
  battery_setup();
  pinMode(WAKEUP_BUTTON, INPUT);
  esp_sleep_enable_ext0_wakeup(GPIO_NUM_34, HIGH); // 1 = High, 0 = Low
#endif // DUMMY_NODE
  setup_data_logger();

  esp_sleep_enable_timer_wakeup(SLEEP_TIME * 1000000);
  delay(random(0, 10) * 1000);
  ble_setup();
  Serial.println("/* ----------------------------- SETUP COMPLETE ----------------------------- */");

  Serial.println("Collecting Data");
  String msg = "N:" + node_type + ',' + "I:" + NODE_ID; // Starting to write message
  msg += "," + fetch_formatted_time();                  // Fetching Time from RTC

// Collecting Sensor Value
#ifdef DUMMY_NODE
  msg += ",T:" + (String)random(0, 100) + ",H:" + (String)random(0, 100);
  msg += ",C:" + (String)random(20, 400);
  msg += ",L:" + (String)random(20, 600);
  msg += ",B:" + (String)random(0, 100);
#else
  msg += collect_temperature_and_humidity_values();
  msg += collect_co2_values();
  msg += collect_lux_values();
  msg += battery_level_percentage();
#endif // DUMMY_NODE

  Serial.println("NODE MSG: " + msg);
  send_data_via_ble("start", external_wakeup, true);
  delay(500);

  if (!send_data_via_ble(msg, external_wakeup, true)) // Sending Data to BLE Device
  {
    Serial.println("\nData Send Failure");
    String sd_msg = "hist," + msg;
    write_historical_data(sd_msg); // If device is not connected, then saving the data in historical data array
  }
  else
  {
    read_historical_data();
    delay(500);
    send_data_via_ble("end", false, true);
  }

#ifndef DUMMY_NODE
  if (wakeup_reason_flag == ESP_SLEEP_WAKEUP_EXT0) // This line is checked only when the device is woken up by external int.
  {
    Serial.println("Waiting for user to enter sleep mode command");
    while (1)
    {
      if (recieved_data_flag)
        if (recieved_data_via_ble())
          break;
      delay(50);
    }
  }
#endif // DUMMY_NODE

  // Serial.println("Raw Battery ADC: " + (String)analogRead(BATTERY_ADC_PIN));// TODO: Uncomment this line when battery ADC needs to be measured.

  Serial.println("Going to Sleep");
  delay(50);
  esp_deep_sleep_start();
}

void loop()
{
}

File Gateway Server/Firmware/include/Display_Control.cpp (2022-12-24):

#ifndef Display_Control_cpp
#define Display_Control_cpp
#include "Arduino.h"
#include "HardwareSerial.h"
#include "Variable_Declaration.h"
#include "Pin_Connection.h"
#include <Battery_Level.cpp>

/* ---------------------------- BASIC DEFINITION ---------------------------- */
HardwareSerial nextionSerial(2);
#define SUPPLY_CONNECTED_PIN CHARGER_INPUT // Power Supply connected to pin
#define GREEN 34784
#define ORANGE 64520
#define RED 63488
bool display_first_boot = true;

/* --------------------------- FUNCTION DEFINITION -------------------------- */
void setup_display(void);
void update_display(bool wifi_status, bool internet_status, bool temp_alert, bool humidity_alert, bool lux_alert, bool co2_alert, String date, String time, uint8_t average_temp, uint8_t average_humidity, uint16_t average_lux, uint16_t average_co2);

/* -------------------------- FUNCTION DECLARATION -------------------------- */
void update_data_on_screen(String param, String cmd, int cmd_value = 0, String cmd_string = "")
{
    String write_message;
    if (cmd_value != 0)
        write_message = param + "." + cmd + "=" + cmd_value;
    else if (cmd_string != "")
        write_message = param + "." + cmd + "=" + "\"" + cmd_string + "\"";
    nextionSerial.print(write_message);
    nextionSerial.write(0xff);
    nextionSerial.write(0xff);
    nextionSerial.write(0xff);
    delay(10);
    Serial.println(param + "." + cmd + "=" + cmd_value + " " + cmd_string);
}

void update_alert_flags(bool alert_mode, String param)
{
    if (alert_mode)
        update_data_on_screen(param, "bco", RED, ""); // Create Alert
    else
        update_data_on_screen(param, "bco", GREEN, ""); // No Alert
}

void set_battery_level(void)
{
    uint8_t battery_level = read_battery_level();
    bool charger_status = digitalRead(SUPPLY_CONNECTED_PIN);
    update_data_on_screen("bat_level", "val", battery_level, "");

    if (battery_level >= 50)
        update_data_on_screen("bat_level", "pco", GREEN, "");
    else if (battery_level >= 20)
        update_data_on_screen("bat_level", "pco", ORANGE, "");
    else
        update_data_on_screen("bat_level", "pco", RED, "");

    if (charger_status)
        update_data_on_screen("supply_pin", "pic", SUPPLY_CONNECTED_ID, "");
    else
        update_data_on_screen("supply_pin", "pic", NO_SUPPLY_CONNECTED_ID, "");
}

void set_wifi_internet_flag(bool wifi_status, bool internet_status)
{
    if (internet_status)
        update_data_on_screen("wifi_status", "pic", INTERNET_CONNECTED_FLAG_ID, "");
    else if (wifi_status)
        update_data_on_screen("wifi_status", "pic", NO_INTERNET_FLAG_CONNECTED_ID, "");
    else
        update_data_on_screen("wifi_status", "pic", NO_WIFI_CONNECTED_FLAG_ID, "");
}
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

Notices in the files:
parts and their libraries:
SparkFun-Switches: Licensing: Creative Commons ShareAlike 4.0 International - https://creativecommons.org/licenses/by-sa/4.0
